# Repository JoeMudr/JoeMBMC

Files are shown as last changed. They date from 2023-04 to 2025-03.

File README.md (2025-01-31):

# JoeM BMC
Originally called "JoeM BMS" is now called "JoeM BMC" Battery Management Controller. Since it's not a complete BMS but only a controller for existing BMS-Modules.
This is the updated version for Teensy 4.0

This project is derived from [Toms SimpBMS code](https://github.com/Tom-evnut). It started as a clone (Software & Hardware) but ended up completely rewritten and redesigned. But you might still find some traces to the original code.

Complete documentation coming soon.

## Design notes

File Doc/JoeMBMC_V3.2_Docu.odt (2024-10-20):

JoeM BMC

Battery Management Controller
V3.2

# Introduction

This BMC (Battery Management Controller) is not a BMS on it’s own. It is designed to control OEM Battery Management Boards, Cell Monitoring Units or Battery Management Systems.

⚠ Although the BMC has been thoroughly tested, this is not a finished product. Some prior knowledge is required for commissioning. Use at your own risk!

# Pin Configuration

| A | B | C | D | E | F | G | H | J | K | L | M
1 | Out8 (PWM) | Out7 (PWM) | Out5 (PWM) | Out6 (PWM) | Out1 (12V) | Out2 (12V) | Out4 (12V) | Out3 (12V) | | | 12V | 12V
2 | BMB RX | BMB TX | Disp. RX | Disp. TX | ASen1 | ASen2 | In4 | In3 | In1 | In2
3 | GND | 5V | GND | 5V | GND | 5V
4 | CAN1-L | CAN1-H | CAN2-L | CAN2-H | 5V | USB D- | USB D+ | GND | | | GND | GND

All pins with the same symbol are internally connected.

All PWM-Outputs are tied to GND.

# Absolute maximum Ratings

Parameter | Symbol | Values | | | Unit
| | Min. | Typ. | Max.
Supply
Supply Voltage | 12V | 6 | 12 | 20* | V
Inputs
Voltage at In1 – In4 | VIN | 6 | 12 | 80 | V
ASen1 / Asen2 | VSen | 0 | - | 5 | V
Outputs
Current through OUT1 – Out4 (High) | IHOUT | - | - | 1 | A
Current through OUT5 – Out8 (Low) | ILOUT | - | - | 1 | A
5V | 5V | - | - | 0.5 | A

*Beware that the high side outputs are tied to the input voltage. It is technically possible to power the BMC with more than 12V. But all components controlled by the BMC on Out1 to Out4 should be able to withstand this high voltage.

# Wiring

## Precautions

- All wires for the power supply (L1,M1,L4,M4) should be 1mm². Add a fuse (10A) to the 12V line. It is not necessary to use both 12V and GND input pins.
- Do not use any other pin except L4 & M4 as your main GND connection!
- Do not feed any 5V pin with voltage! When intending to wire up and connect USB to your PC or any device that provides 5V over USB, do not connect the 5V pin! It might damage your USB-Port.
- Add 1A fuses to the outputs and use appropriate wire sizes.
- Use shielded wires for signals. Connect shielding to GND.

## Tesla Model S / X

Tesla Modules are daisy chained together. You start at the BMC Pin B2 (TX) which connects to the Molex connector of the Tesla board on Pin 2 or 7 (RX). Next you connect Pin 4 or Pin 9 (TX) to the next boards RX and so on. From the last board you connect the TX back to the BMC on Pin A2 (RX).

For power supply of the Tesla board use Pin B3 (5V) and A3 (GND) which connect to Pin 1 or 5 (5V) and Pin 3 or 8 (GND) respectively.

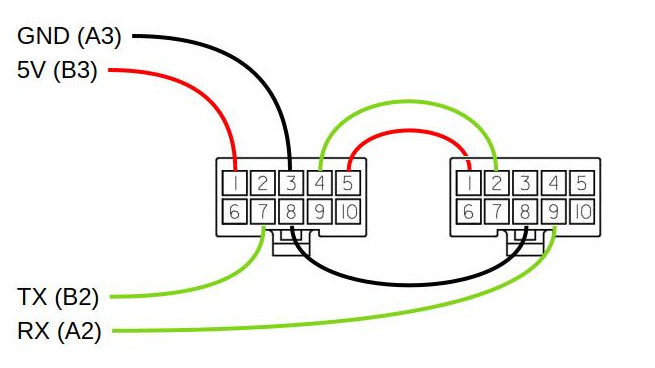
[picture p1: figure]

## VW MEB

Since the CMU connectors are not available on the free market, it’s important you keep the original connectors!

VW MEB Modules use CAN for communication. Therefor the CMUs must be connected in a kind of chain. One of the CMUs marks the end of the chain where a termination resistor must be activated.

Wire colors:

PIN | Function
1 | GND
2 | GND
3 | --
4 | TermR
5 | --
6 | TermR
7 | CAN High
8 | CAN High
9 | CAN Low
10 | CAN Low
11 | 12V
12 | 12V

Green-White 12V
Brown GND
Orange-Blue CAN High
Orange-Brown CAN Low

To use the termination resistor for example connect Pin 4 to Pin 7 and Pin 6 to Pin 9.

## BMW i3

# Configuration over USB

## Connecting via Terminal

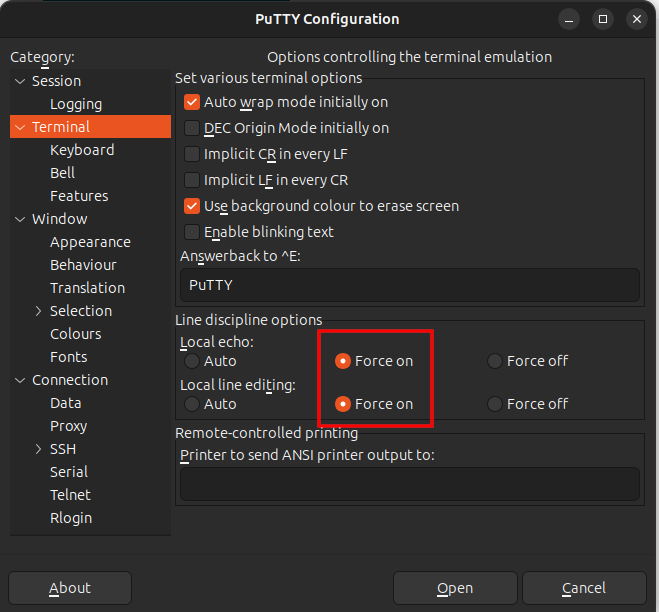
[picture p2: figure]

For a proper connection to the BMC use a terminal software such as putty (https://www.putty.org/). You can also use the Serial Monitor of the Arduino IDE. It’s important that the terminal software is set to use local echo and local line editing! Arduino IDE does this by default. In putty you find these settings under “Terminal”.

## Default Screen

Hotkeys:

b – toggle Modules / Cells display

o – toggle Output display

m – open Menu

## Configuration Menu

## Firmware Update

To update the BMC you need the latest firmware file from https://github.com/JoeMudr/JoeMBMC.
You also need the Teensy loader software from https://www.pjrc.com/teensy/loader.html.

Start the Teensy loader software and chose File → Open HEX File and select the Firmware.hex file.

Connect the BMC via USB. And open a Terminal. Press [M]+[Enter] to enter the main menu. In the main menu press [X]+[Enter]. This will reboot the micro controller to load the new firmware.

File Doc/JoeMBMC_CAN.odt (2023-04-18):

# CAN Messages

CAN ID 0x351 (send 1/sec) Limits
Byte | | Unit | Scale
1 | Charge Voltage High Byte | V | 0,1
2 | Charge Voltage Low Byte
3 | Charge Current High Byte | A | 0,1
4 | Charge Current Low Byte
5 | Discharge Current High Byte | A | 0,1
6 | Discharge Current Low Byte
7 | Discharge Voltage High Byte | V | 0,1
8 | Discharge Voltage Low Byte

CAN ID 0X355 (send 1/sec) SOC / SOH
Byte | | Unit | Scale
1 | SOC LowByte | % | 1
2 | SOC HighByte
3 | SOH LowByte | % | 1
4 | SOH HighByte
5 | SOC LowByte | % | 0,1
6 | SOC HighByte
7
8

CAN ID 0X356 (send 1/sec) Status
Byte | | Unit | Scale
1 | Pack Voltage LowByte | V | 0,01
2 | Pack Voltage HighByte
3 | Current LowByte | A | 0,1
4 | Current HighByte
5 | Av. Temperature LowByte | °C | 0,1
6 | Av. Temperature HighByte
7 | -
8 | -

CAN ID 0X35A (send 1/sec) Warnings / Alarms
Byte | | Unit | Scale
1 | alarm[0] | | 0 = OK, 1=Error
2 | alarm[1]
3 | alarm[2]
4 | alarm[3]
5 | warning[0] | | 0 = OK, 1=Error
6 | warning[1]
7 | warning[2]
8 | warning[3]

Bit | alarm[0] | alarm[1] | alarm[2] | alarm[3]
1 | - | Under Temperature | - | Cell Imbalance
2 | - | - | - | -
3 | Cell Over Voltage | - | - | -
4 | - | - | - | -
5 | Cell Low Voltage | - | - | -
6 | - | - | - | -
7 | Over Temperature | - | - | -
8 | - | - | - | -

Bit | warning[0] | warning[1] | warning[2] | warning[3]
1 | - | Under Temperature | - | -
2 | - | - | - | -
3 | Cell Over Voltage | - | - | -
4 | - | - | - | -
5 | Cell Low Voltage | - | - | -
6 | - | - | - | -
7 | Over Temperature | - | - | -
8 | - | - | - | -

CAN ID 0X372 (send 1/sec) Number of Modules
Byte | | Unit | Scale
1 | Number of Modules LowByte
2 | Number of Modules HighByte

CAN ID 0X373 (send 1/sec) Extreme Values
Byte | | Unit | Scale
1 | Low Cell Volt LowByte | V
2 | Low Cell Volt HighByte
3 | High Cell Volt LowByte | V
4 | High Cell Volt HighByte
5 | Low Temp. LowByte | K
6 | Low Temp. HighByte
7 | High Temp. LowByte | K
8 | High Temp. HighByte

CAN ID 0X372 (send 1/sec) Installed Capacity
Byte | | Unit | Scale
1 | Installed Capacity LowByte | Ah
2 | Installed Capacity HighByte

Plug | | BMS | | C
Plug connect
| AC conn / A max (contin.) →
| | Chk Cond. stat Charge
| ← Charge start
Close lock Chk Lock? charge en.
| Status →
| | Chk Stat.
| | | Charge start / A max →
| ← Charge stop | | Charge stop / A max = 0 →
Vehicle detec. Unlock?
Plug unconn. | Status (contin.) → | Chk if pres. Else → Err.

CAN Plug:

AC conn, Amax,

Status | Red LED | Green LED
norm | off | off
Plug connected | Blink slow | off
Charging / locked | on | Blink slow
Charged / locked | on | on
error | Blink fast | off

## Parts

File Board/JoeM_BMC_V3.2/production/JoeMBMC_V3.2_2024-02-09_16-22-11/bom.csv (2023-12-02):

Designator | Footprint | Quantity | Value | LCSC Part #
C1, C13, C14, C4 | 0805 | 4 | 100nF | C49678
C10, C11, C12, C9 | 0402 | 4 | 100p | C1546
C2, C3 | 0805 | 2 | 10uF | C15850
C5, C6, C7, C8 | C_Elec_6.3x7.7 | 4 | 100uF | C3001246
D1, D2, D3, D4 | D_SOD-123F | 4 | DIODE | C37049
D5, D6 | SOT-23 | 2 | NUP2105L | C284104
J1 | 5007620481 | 1 | 5007620481
J2 | PinHeader_1x02_P2.54mm_Vertical | 1 | CAN2_T
J3 | PinHeader_1x02_P2.54mm_Vertical | 1 | CAN1_T
Q1, Q2 | SO-8_IRF956 | 2 | BSO615NG | C693398
Q3 | TO-252-2 | 1 | P-Chanel Mosfet | C416264
R1, R10, R12, R14, R16, R18, R21, R26, R27, R28, R29, R30, R6, R7, R8, R9 | 0805 | 16 | 10k | C17414
R11, R13, R15, R17 | 0805 | 4 | 220 | C17557
R19, R22 | 0805 | 2 | 20k | C4328
R2, R3, R4, R5 | 0805 | 4 | 4.7k | C17673
R24, R25 | 0805 | 2 | 120 | C17437
R31, R32, R33, R34 | 0805 | 4 | 47k | C17713
S1 | PG-DSO-14-40_EP | 1 | BTS5200-4 | C534815
U1 | Teensy40_JoeMBMS | 1 | Teensy4.0
U2, U5 | SOIC-8_3.9x4.9mm_P1.27mm | 2 | SN65HVD230 | C12084
U3 | Converter_DCDC_RECOM_R-78E-0.5_THT | 1 | DCDC 5V
U4 | TLP293-4 | 1 | IS281-4 | C89878
U6 | Converter_DCDC_RECOM_R-78E-0.5_THT | 1 | DCDC 3.3V
U7, U8 | SOT-23-6 | 2 | Level Shifter 5V to 3V | C7843

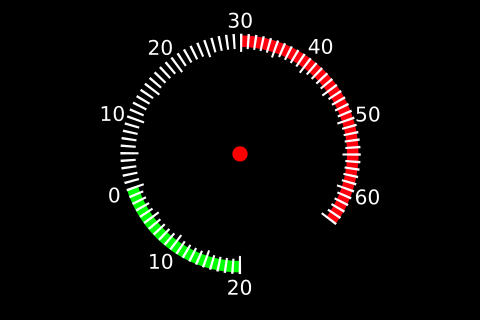
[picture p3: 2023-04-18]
BMSdisplay/components/Dash1_bg.png

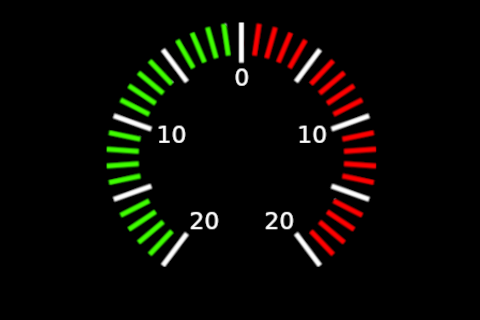
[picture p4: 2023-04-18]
BMSdisplay/components/Dash1_bg2.png

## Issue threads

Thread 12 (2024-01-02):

charge current limit via hardware

JoeMudr, 2024-01-02:
on the charge controller make the charge current selectable.
--> transmit to BMC

JoeMudr, 2024-03-24:
Feature for charge controller. Closed.

Closed 2024-03-24.

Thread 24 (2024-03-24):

Add Heating / Cooling request to BMC_Std CAN; Add option to menu

JoeMudr, 2024-03-24:
- Temperature Values configurable in menu

JoeMudr, 2024-03-26:
Current Implementation: Cooling/heating request can be read from temperature warnings from CAN ID 0x35A.
Warnings are raised from over/under temperature with warning offset configurable in the menu.
--> Maybe add separate options for temperature warnings.

JoeMudr, 2024-03-28:
see above

Closed 2024-03-28.

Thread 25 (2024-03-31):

Add optocouplers to all digital inputs

JoeMudr, 2024-03-31:
- replace level converter on serial lines
- add between CAN-Transceiver & Teensy

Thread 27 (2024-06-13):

current sensing on output

JoeMudr, 2024-06-13:
Add current sensing capabilities on all outputs for fault detection:
* contactor failure
* overcurrent detection

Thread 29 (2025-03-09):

Slowly increase charge current after 0A

JoeMudr, 2025-03-09:
Full charge current after Stat_Charged might overshoot charge voltage setpoint on slow inverters.
Make BMC slowly increase the charge current over a certain time span (30s?) when coming from 0A.

Closed 2025-03-23.

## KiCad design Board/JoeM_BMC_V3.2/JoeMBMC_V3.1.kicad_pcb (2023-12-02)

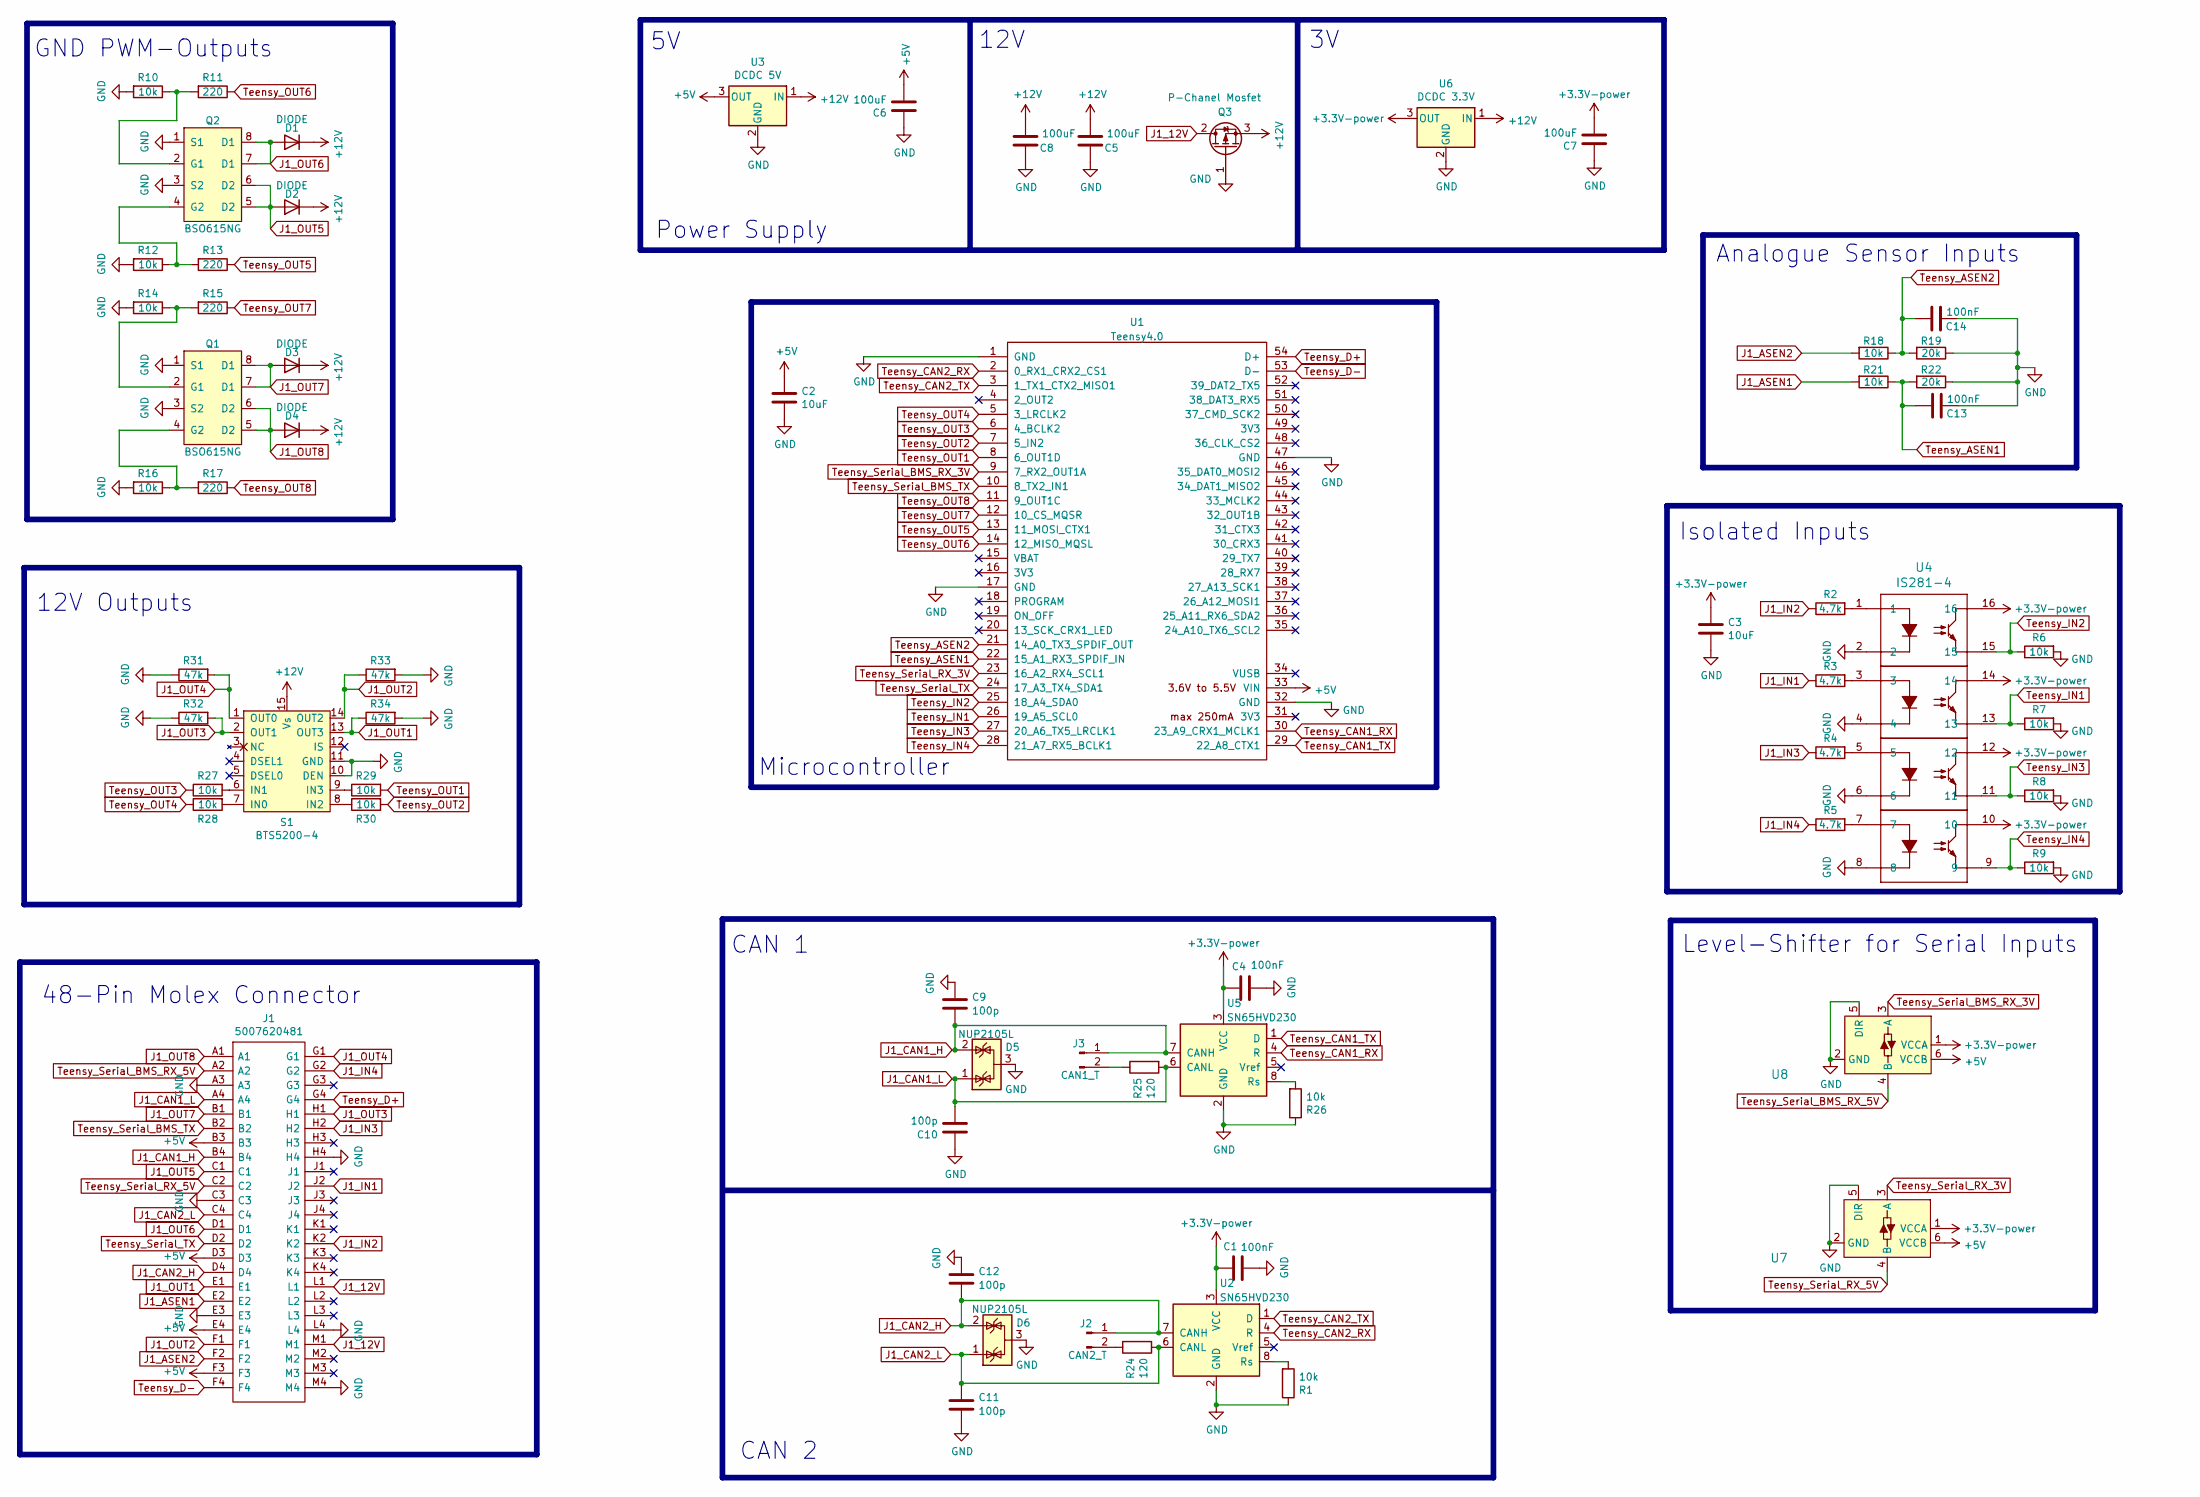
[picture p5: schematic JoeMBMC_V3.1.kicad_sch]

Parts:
C1, C4, C13, C14: 100nF; C_0805_2012Metric; LCSC C49678
C2, C3: 10uF; C_0805_2012Metric; LCSC C15850
C5, C6, C7, C8: 100uF; C_Elec_6.3x7.7; LCSC C3001246
C9, C10, C11, C12: 100p; C_0402_1005Metric; LCSC C1546
D1, D2, D3, D4: DIODE; D_SOD-123F; LCSC C8598
D5, D6: NUP2105L; SOT-23; LCSC C284104
J1: 5007620481; Manufacturer_Part_Number 5007620481
J2: CAN2_T; PinHeader_1x02_P2.54mm_Vertical
J3: CAN1_T; PinHeader_1x02_P2.54mm_Vertical
Q1, Q2: BSO615NG; SO-8_IRF956; LCSC C693398
Q3: P-Chanel Mosfet; TO-252-2; LCSC C416264
R1, R6, R7, R8, R9, R10, R12, R14, R16, R18, R21, R26, R27, R28, R29, R30: 10k; R_0805_2012Metric; LCSC C17414
R2, R3, R4, R5: 4.7k; R_0805_2012Metric; LCSC C17673
R11, R13, R15, R17: 220; R_0805_2012Metric; LCSC C17557
R19, R22: 20k; R_0805_2012Metric; LCSC C4328
R24, R25: 120; R_0805_2012Metric; LCSC C17437
R31, R32, R33, R34: 47k; R_0805_2012Metric; LCSC C17713
S1: BTS5200-4; PG-DSO-14-40_EP; LCSC C534815
U1: Teensy4.0; Teensy40_JoeMBMS
U2, U5: SN65HVD230; SOIC-8_3.9x4.9mm_P1.27mm; LCSC C12084
U3: DCDC 5V; Converter_DCDC_RECOM_R-78E-0.5_THT
U4: IS281-4; TLP293-4; LCSC C89878
U6: DCDC 3.3V; Converter_DCDC_RECOM_R-78E-0.5_THT
U7, U8: Level Shifter 5V to 3V; SOT-23-6; LCSC C7843

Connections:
+3V3: C1.2, C3.2, C4.2, C7.1, U2.3 (VCC), U4.10, U4.12, U4.14, U4.16, U5.3 (VCC), U6.3 (OUT), U7.1 (VCCA), U8.1 (VCCA); also elsewhere on the board
+5V: C2.2, C6.1, J1.B3, J1.D3, J1.E4, J1.F3, U1.33 (VIN), U3.3 (OUT), U7.6 (VCCB), U8.6 (VCCB); also elsewhere on the board
+12V: C5.1, C8.1, D1.1 (K), D2.1 (K), D3.1 (K), D4.1 (K), Q3.3 (S), S1.15 (Vs), U3.1 (IN), U6.1 (IN); also elsewhere on the board
GND: C1.1, C2.1, C3.1, C4.1, C5.2, C6.2, C7.2, C8.2, C9.1, C10.1, C11.2, C12.1, C13.1, C14.1, D5.3 (A), D6.3 (A), J1.A3, J1.C3, J1.E3, J1.H4, J1.L4, J1.M4, Q1.1 (S1), Q1.3 (S2), Q2.1 (S1), Q2.3 (S2), Q3.1 (G), R1.1, R6.2, R7.2, R8.2, R9.2, R10.2, R12.2, R14.2, R16.2, R19.1, R22.1, R26.1, R31.1, R32.1, R33.2, R34.2, S1.10 (DEN), S1.11 (GND), U1.1 (GND), U1.17 (GND), U1.32 (GND), U1.47 (GND), U2.2 (GND), U3.2 (GND), U4.2, U4.4, U4.6, U4.8, U5.2 (GND), U6.2 (GND), U7.2 (GND), U7.5 (DIR), U8.2 (GND), U8.5 (DIR)
J1_12V: J1.L1, J1.M1, Q3.2 (D)
J1_ASEN1: J1.E2, R21.2
J1_ASEN2: J1.F2, R18.2
J1_CAN1_H: C9.2, D5.2 (K), J1.B4, J3.1, U5.7 (CANH)
J1_CAN1_L: C10.2, D5.1 (K), J1.A4, R25.2, U5.6 (CANL)
J1_CAN2_H: C12.2, D6.2 (K), J1.D4, J2.1, U2.7 (CANH)
J1_CAN2_L: C11.1, D6.1 (K), J1.C4, R24.2, U2.6 (CANL)
J1_IN1: J1.J2, R3.1
J1_IN2: J1.K2, R2.1
J1_IN3: J1.H2, R4.1
J1_IN4: J1.G2, R5.1
J1_OUT1: J1.E1, R34.1, S1.13 (OUT3)
J1_OUT2: J1.F1, R33.1, S1.14 (OUT2)
J1_OUT3: J1.H1, R32.2, S1.2 (OUT1)
J1_OUT4: J1.G1, R31.2, S1.1 (OUT0)
J1_OUT5: D2.2 (A), J1.C1, Q2.5 (D2), Q2.6 (D2)
J1_OUT6: D1.2 (A), J1.D1, Q2.7 (D1), Q2.8 (D1)
J1_OUT7: D3.2 (A), J1.B1, Q1.7 (D1), Q1.8 (D1)
J1_OUT8: D4.2 (A), J1.A1, Q1.5 (D2), Q1.6 (D2)
unnamed: J2.2, R24.1
unnamed: J3.2, R25.1
unnamed: Q1.2 (G1), R14.1, R15.2
unnamed: Q1.4 (G2), R16.1, R17.2
unnamed: Q2.2 (G1), R10.1, R11.2
unnamed: Q2.4 (G2), R12.1, R13.2
unnamed: R2.2, U4.1
unnamed: R3.2, U4.3
unnamed: R4.2, U4.5
unnamed: R5.2, U4.7
unnamed: R28.2, S1.7 (IN0)
unnamed: R27.2, S1.6 (IN1)
unnamed: R30.1, S1.8 (IN2)
unnamed: R29.1, S1.9 (IN3)
unnamed: R1.2, U2.8 (Rs)
unnamed: R26.2, U5.8 (Rs)
Teensy_ASEN1: C13.2, R21.1, R22.2, U1.22 (15_A1_RX3_SPDIF_IN)
Teensy_ASEN2: C14.2, R18.1, R19.2, U1.21 (14_A0_TX3_SPDIF_OUT)
Teensy_CAN1_RX: U1.30 (23_A9_CRX1_MCLK1), U5.4 (R)
Teensy_CAN1_TX: U1.29 (22_A8_CTX1), U5.1 (D)
Teensy_CAN2_RX: U1.2 (0_RX1_CRX2_CS1), U2.4 (R)
Teensy_CAN2_TX: U1.3 (1_TX1_CTX2_MISO1), U2.1 (D)
Teensy_D+: J1.G4, U1.54 (D+)
Teensy_D-: J1.F4, U1.53 (D-)
Teensy_IN1: R7.1, U1.26 (19_A5_SCL0), U4.13
Teensy_IN2: R6.1, U1.25 (18_A4_SDA0), U4.15
Teensy_IN3: R8.1, U1.27 (20_A6_TX5_LRCLK1), U4.11
Teensy_IN4: R9.1, U1.28 (21_A7_RX5_BCLK1), U4.9
Teensy_OUT1: R29.2, U1.8 (6_OUT1D)
Teensy_OUT2: R30.2, U1.7 (5_IN2)
Teensy_OUT3: R27.1, U1.6 (4_BCLK2)
Teensy_OUT4: R28.1, U1.5 (3_LRCLK2)
Teensy_OUT5: R13.1, U1.13 (11_MOSI_CTX1)
Teensy_OUT6: R11.1, U1.14 (12_MISO_MQSL)
Teensy_OUT7: R15.1, U1.12 (10_CS_MQSR)
Teensy_OUT8: R17.1, U1.11 (9_OUT1C)
Teensy_Serial_BMS_RX_3V: U1.9 (7_RX2_OUT1A), U8.3 (A)
Teensy_Serial_BMS_RX_5V: J1.A2, U8.4 (B)
Teensy_Serial_BMS_TX: J1.B2, U1.10 (8_TX2_IN1)
Teensy_Serial_RX_3V: U1.23 (16_A2_RX4_SCL1), U7.3 (A)
Teensy_Serial_RX_5V: J1.C2, U7.4 (B)
Teensy_Serial_TX: J1.D2, U1.24 (17_A3_TX4_SDA1)

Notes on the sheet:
Analogue Sensor Inputs
GND PWM-Outputs
48-Pin Molex Connector
CAN 2
CAN 1
12V Outputs
Isolated Inputs
Microcontroller
Power Supply
12V
Level-Shifter for Serial Inputs

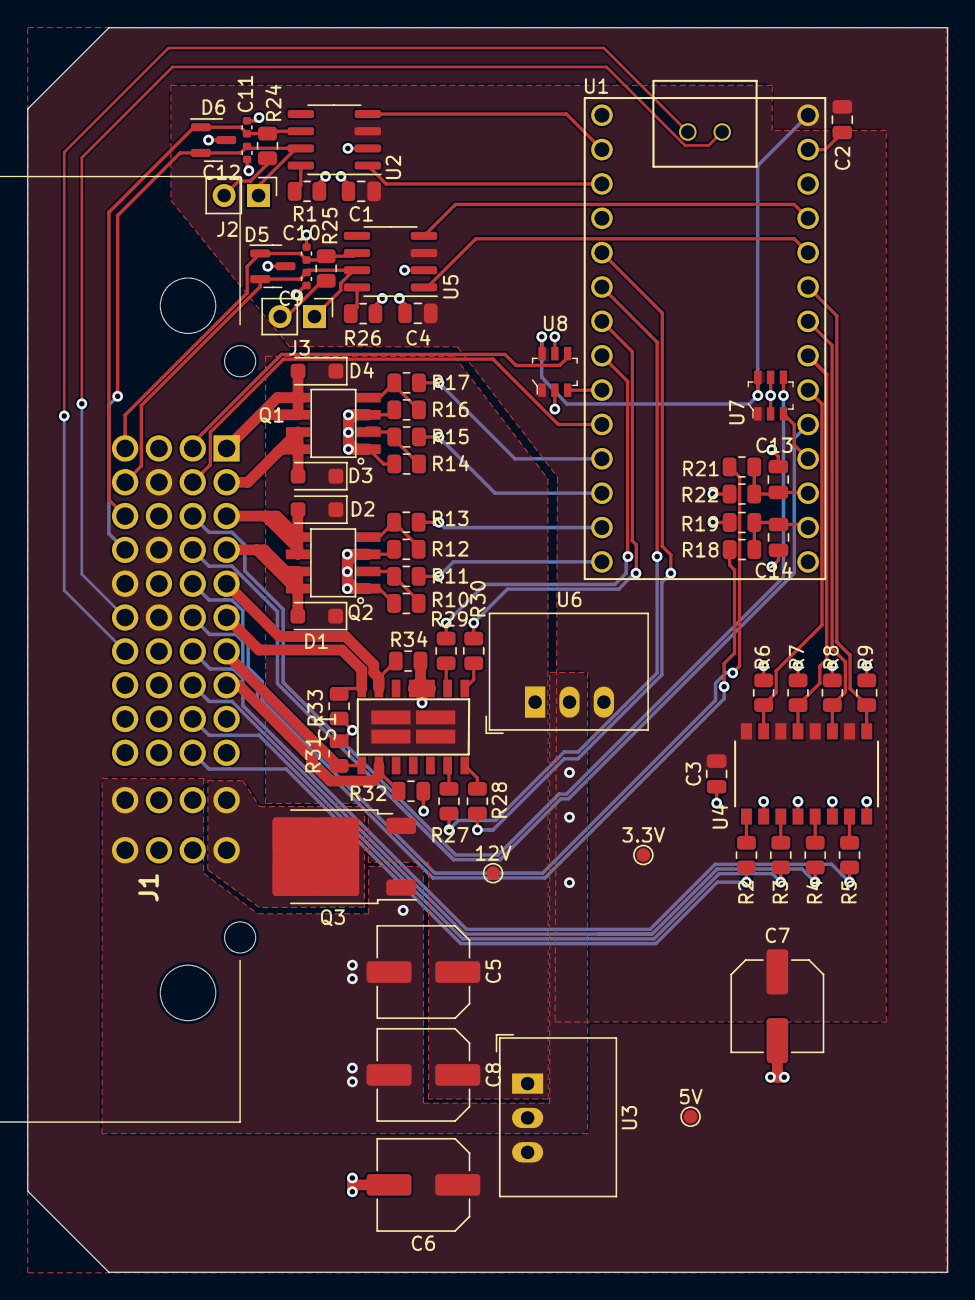
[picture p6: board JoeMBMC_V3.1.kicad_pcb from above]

Board: 2 copper layers, 68.0 x 92.0 mm, 70 parts (0 on the bottom side), 65 nets.

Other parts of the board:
3.3V, 5V, 12V: TestPoint_Pad_D1.0mm

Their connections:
+3V3: 3.3V.1; also elsewhere on the board
+5V: 5V.1; also elsewhere on the board
+12V: 12V.1; also elsewhere on the board

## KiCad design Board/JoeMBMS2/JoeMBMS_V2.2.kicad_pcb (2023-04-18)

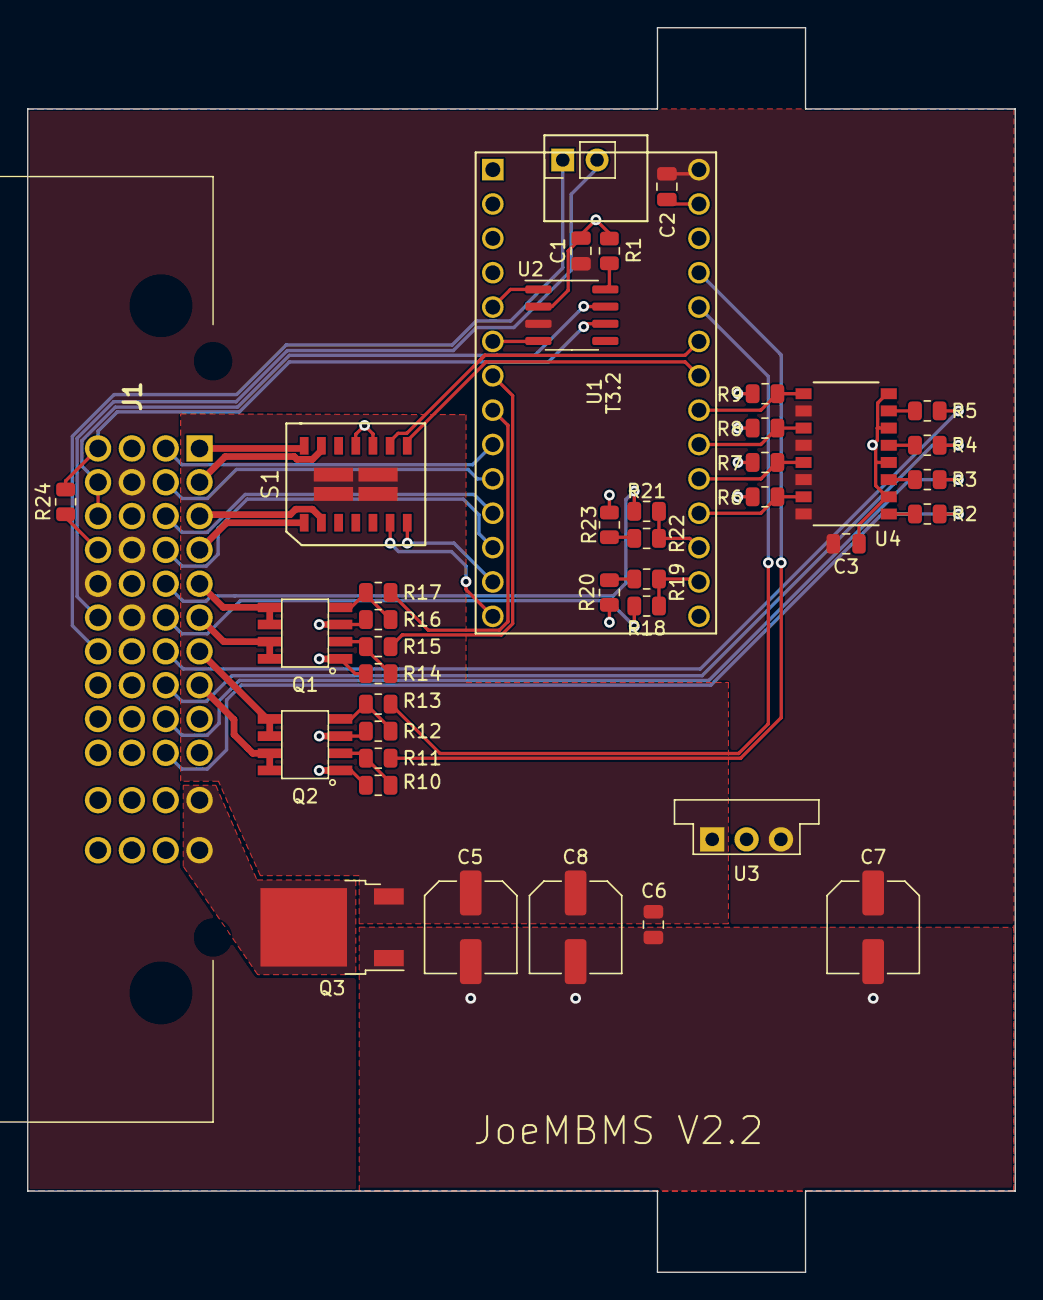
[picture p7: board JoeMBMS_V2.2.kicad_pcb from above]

Board: 2 copper layers, 73.0 x 92.0 mm, 40 parts (0 on the bottom side), 52 nets.

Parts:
C1: 100nF; C_0805_2012Metric
C2, C3, C6: 10uF; C_0805_2012Metric
C5, C7, C8: 100uF; C_Elec_6.3x7.7
J1: 5007620481
Q1, Q2: BSO615NG; SO-8_IRF956
Q3: P-Chanel Mosfet; TO-252-2
R1, R6, R7, R8, R9, R10, R12, R14, R16, R18, R19, R20, R21, R22, R23: 10k; R_0805_2012Metric
R2, R3, R4, R5: 4.7k; R_0805_2012Metric
R11, R13, R15, R17: 220; R_0805_2012Metric
R24: 120; R_0805_2012Metric
S1: BTS5200-4; PG-DSO-14-40_EP
U1: Teensy3.2; Teensy30_31_32_LC_Mod
U2: SN65HVD251; SOIC-8_3.9x4.9mm_P1.27mm
U3: DCDC 5V; Converter_DCDC_muRata_OKI-78SR_Vertical
U4: IS281-4; TLP293-4

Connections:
+12V: C5.1, C6.2, C8.1, Q3.3 (S), S1.15 (Vs), U3.1 (IN)
GND: C1.1, C2.1, C3.1, C5.2, C6.1, C7.2, C8.2, J1.A3, J1.C3, J1.E3, J1.H4, J1.L4, J1.M4, Q1.1 (S1), Q1.3 (S2), Q2.1 (S1), Q2.3 (S2), Q3.1 (G), R1.1, R6.2, R7.2, R8.2, R9.2, R10.2, R12.2, R14.2, R16.2, R20.1, R23.1, S1.10 (DEN), S1.11 (GND), U1.1 (GND), U1.32 (AGND), U2.2 (GND), U3.2 (GND), U4.2, U4.4, U4.6, U4.8
J1_12V: J1.L1, J1.M1, Q3.2 (D)
J1_ASEN1: J1.E2, R21.2
J1_ASEN2: J1.F2, R18.2
J1_CANH: J1.B4, J1.C4, U2.7 (CANH)
J1_CANL: J1.A4, R24.2, U2.6 (CANL)
J1_CAN_T_2: J1.D4, R24.1
J1_IN1: J1.J2, R3.1
J1_IN2: J1.K2, R2.1
J1_IN3: J1.H2, R4.1
J1_IN4: J1.G2, R5.1
J1_OUT1: J1.D1, S1.1 (OUT0)
J1_OUT2: J1.C1, S1.2 (OUT1)
J1_OUT3: J1.A1, S1.14 (OUT2)
J1_OUT4: J1.B1, S1.13 (OUT3)
J1_OUT5: J1.G1, Q2.5 (D2), Q2.6 (D2)
J1_OUT6: J1.H1, Q2.7 (D1), Q2.8 (D1)
J1_OUT7: J1.F1, Q1.7 (D1), Q1.8 (D1)
J1_OUT8: J1.E1, Q1.5 (D2), Q1.6 (D2)
J1_RX2: J1.C2, U1.11 (9_RX2_CS_PWM)
J1_TX2: J1.D2, U1.12 (10_TX2_CS_PWM)
unnamed: Q1.2 (G1), R14.1, R15.2
unnamed: Q1.4 (G2), R16.1, R17.2
unnamed: Q2.2 (G1), R10.1, R11.2
unnamed: Q2.4 (G2), R12.1, R13.2
unnamed: R1.2, U2.8 (Rs)
unnamed: R2.2, U4.1
unnamed: R3.2, U4.3
unnamed: R4.2, U4.5
unnamed: R5.2, U4.7
unnamed: R19.1, R20.2
unnamed: R22.1, R23.2
Teensy_ASEN1: R21.1, R22.2, U1.22 (15_A1_CS_Touch)
Teensy_ASEN2: R18.1, R19.2, U1.21 (14_A0_SCK)
Teensy_IN1: R7.1, U1.24 (17_A3_SDA0_Touch), U4.13
Teensy_IN2: R6.1, U1.23 (16_A2_SCL0_Touch), U4.15
Teensy_IN3: R8.1, U1.25 (18_A4_SDA0_Touch), U4.11
Teensy_IN4: R9.1, U1.26 (19_A5_SCL0_Touch), U4.9
Teensy_OUT1: S1.7 (IN0), U1.13 (11_DOUT)
Teensy_OUT2: S1.6 (IN1), U1.14 (12_DIN)
Teensy_OUT3: S1.8 (IN2), U1.27 (20_A6_CS_PWM)
Teensy_OUT4: S1.9 (IN3), U1.28 (21_A7_RX1_CS_PWM)
Teensy_OUT5: R13.1, U1.29 (22_A8_Touch_PWM)
Teensy_OUT6: R11.1, U1.30 (23_A9_Touch_PWM)
Teensy_OUT7: R15.1, U1.7 (5_TX1_PWM)
Teensy_OUT8: R17.1, U1.8 (6_PWM)
Teensy_RX: U1.6 (4_RX_PWM), U2.4 (R)
Teensy_RX3: J1.A2, U1.9 (7_RX3_DOUT)
Teensy_TX: U1.5 (3_TX_PWM), U2.1 (D)
Teensy_TX3: J1.B2, U1.10 (8_TX3_DIN)
Teensy_VUSB: C1.2, C2.2, C3.2, C7.1, J1.B3, J1.D3, J1.E4, J1.F3, U1.33 (Vin), U2.3 (VCC), U3.3 (OUT), U4.10, U4.12, U4.14, U4.16

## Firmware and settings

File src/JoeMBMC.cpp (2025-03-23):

/*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
  THE SOFTWARE IS PROVIDED "AS IS", WITHOUT WARRANTY OF ANY KIND,
  EXPRESS OR IMPLIED, INCLUDING BUT NOT LIMITED TO THE WARRANTIES OF
  MERCHANTABILITY, FITNESS FOR A PARTICULAR PURPOSE AND NONINFRINGEMENT.
  IN NO EVENT SHALL THE AUTHORS OR COPYRIGHT HOLDERS BE LIABLE FOR ANY
  CLAIM, DAMAGES OR OTHER LIABILITY, WHETHER IN AN ACTION OF CONTRACT,
  TORT OR OTHERWISE, ARISING FROM, OUT OF OR IN CONNECTION WITH THE
  SOFTWARE OR THE USE OR OTHER DEALINGS IN THE SOFTWARE.
*/

#include <JoeMBMC.h>
#include <Arduino.h>
#include <EEPROM.h>
#include <ADC.h>          //https://github.com/pedvide/ADC
#include <Filters.h>      //https://github.com/JonHub/Filters
#include <Watchdog_t4.h>  //https://github.com/tonton81/WDT_T4

Stream* activeSerial = &Serial_USB;

/////Version Identifier/////////
uint32_t firmver = 250323;

uint32_t Uptime = 0;

BMSManager bms;
EEPROMSettings settings;

//Curent filter//
byte filterFrequency = 5 ;
FilterOnePole lowpassFilter( LOWPASS, filterFrequency );

//BMC wiring//
//#define doesn't work here because Pins are used in Arrays below.
const byte IN_ACUR2 = A0;      // analogue current sensor 1
const byte IN_ACUR1 = A1;      // analogue current sensor 2
const byte IN_BOD = A10;       // brownout detection on ADC pin [ToDo]
const byte IN1_Key = 19;    // input 1 - high active
const byte IN2_Gen = 18;    // input 2 - high active
const byte IN3_AC = 20;     // input 3 - high active
const byte IN4_HVIL = 21;   // input 4 - high active
const byte OUT1 = 6;        // output 1 - high active
const byte OUT2 = 5;        // output 2 - high active
const byte OUT3 = 4;        // output 3 - high active
const byte OUT4 = 3;        // output 4 - high active
const byte OUT5 = 11;       // output 5 - Low active / PWM
const byte OUT6 = 12;       // output 6 - Low active / PWM
const byte OUT7 = 10;       // output 7 - Low active / PWM
const byte OUT8 = 9;        // output 8 - Low active / PWM
const byte LED = 13;

// uint32_t LED_Timer = 0;

byte BMC_Stat = 0;

//Serial Menu
bool menu_load = 0;

//Errors
uint32_t error_timer = 0;

byte Settings_unsaved = 0;

//variables for output control
uint16_t pwmfreq = 18000;//pwm frequency

uint16_t chargecurrent = 0;       // in 0,1A
uint16_t chargecurrentFactor = 0; // in%, correction factor, when using multiple chargers
uint16_t discurrent = 0;          // in 0,1A

/*
// SMA/Victron style Alarms & Warnings
// even Bits --> Alarm / Warning raised
// odd Bits --> Alarm / Warning cleared
[0] (7/6) hight Temp.          (5/4) low Voltage           (3/2) high Voltage           (1/0) general Alarm
[1] (7/6) high current         (5/4) low Temp. charge      (3/2) high Temp. charge      (1/0) low Temp.
[2] (7/6) Internal Failure     (5/4) battery short circuit (3/2) contactor problem      (1/0) high current charge
[3] (1/0) Cell Imbalance
*/
byte alarm[4],warning[4] = {0, 0, 0, 0};

// uint32_t warning_timer = 0;

unsigned char bmcname[8] = {'J', 'O', 'E', 'M', ' ', 'B', 'M', 'C'};
unsigned char bmcmanu[8] = {'J', 'O', 'E', 'M', ' ', 'T', 'E', 'C'};

//int32_t ISAVoltage1, ISAVoltage2, ISAVoltage3 = 0; //mV only with ISAscale sensor

uint32_t BMSLastRead = 0; // [ToDo] not used

//variables for current/capacity calulation
uint16_t Sen_AnalogueRawValue;
int32_t currentact = 0; // mA
int32_t currentlast = 0; // mA
int32_t RawCur;
int32_t mampsecond = 0; // Range 0 = full to settings.cap * -1 = empty
volatile int32_t mampsecondTimer = 0;
byte Sen_Analogue_active_Nr = 1; // active analogue sensor: 1 = Sensor 1; 2 = Sensor 2
int16_t TCAP = 0; //Temperature corrected Capacity in Ah including settings.Pstrings!
int16_t TCAP_Wh = 0;
//Variables for SOC calc
byte SOC = 100; //State of Charge

//charger variables Prusa
byte maxac1 = 16; //Shore power 16A per charger; only used for prusa charger
byte maxac2 = 10; //Generator Charging; only used for prusa charger
const int16_t chargerid1 = 0x618; //bulk chargers (brusa)
const int16_t chargerid2 = 0x638; //finishing charger (brusa)
uint16_t chargerendbulk = 0; //mV before Charge Voltage to turn off the bulk charger/s
uint16_t chargerend = 0; //mV before Charge Voltage to turn off the finishing charger/s


bool v_CAN_Charger_Active = false; // global variable for CAN-Based chargers
u_int32_t v_CAN_Charger_Active_Timer = 0; // Reset-timer for v_CAN_Charger_Active


//variables
byte storagemode = 0;
byte precharged = 0;

byte output_debug_counter = 0;

//Output Control
byte cont_pulltime = 255;

/*
Array for looping through outputs
OUT1 = 1, OUT2 = 2 ...
*/
const byte *Outputs[9] = {0,&OUT1,&OUT2,&OUT3,&OUT4,&OUT5,&OUT6,&OUT7,&OUT8};

/*
Array for function states & according timers for PWMs (full pull->reduced power)
[0][x] Function State (High/Low); [1][x] timer
*/
#define Out_States_Max 13
byte Out_States[2][Out_States_Max] = {{0,0,0,0,0,0,0,0,0,0,0,0,0},{0,cont_pulltime,cont_pulltime,cont_pulltime,0,0,0,0,0,0,0,0,0}}; 

/*
Text desctiptions for output funktions:
0 - undefined, 
1 - precharge Contactor, 
2 - positive Contactor, 
3 - negative Contactor, 
4 - Discharge enable, 
5 - Charge Enable, 
6 - Error, 
7 - Warning, 
8 - Error & Warning 
9 - Heating enable, 
10 - Cooling enable, 
11 - Gauge
12 - Balance enable
*/
String Out_Functions[] = {
  "undefined", 
  "precharge Cont.", 
  "positive Cont.", 
  "negative Cont.", 
  "Discharge enable", 
  "Charge enable", 
  "Error", 
  "Warning", 
  "Error & Warning",
  "Heating enable", 
  "Cooling enable", 
  "Gauge",
  "Balance enable"
};

//IDs for Array above
#define Out_undefined 0
#define Out_Cont_Precharge 1
#define Out_Cont_Pos 2
#define Out_Cont_Neg 3
#define Out_Discharge 4
#define Out_Charge 5
#define Out_Error 6
#define Out_Warning 7
#define Out_Err_Warn 8
#define Out_Heating 9
#define Out_Cooling 10
#define Out_Gauge 11
#define Out_Balance 12

//uint32_t Out_PWM_fullpull_Timer = 0; // PWM Timer

// CAN
FlexCAN_T4<CAN1> can1;
FlexCAN_T4<CAN2> can2;

// uint32_t CAN_BMC_Std_send_Timer = 0;

// Debugging modes
bool debug = 1;
bool debug_Input = 0;   // read digital inputs
bool debug_Output = 0;  // check outputs
bool debug_CAN1 = 0;    // view can frames
bool debug_CAN2 = 0;    // view can frames
bool debug_Gauge = 0;
byte  debug_Gauge_val = 0;
uint32_t debug_Gauge_timer = 0;
bool debug_Cur = 0;
bool debug_CSV = 0;
byte debug_Digits = 2; // amount of digits behind decimal for voltage reading

ADC *adc = new ADC(); // adc object

// TCU Variables
byte TCU_Pump = 0;
byte TCU_Cool = 0;
byte TCU_Heat = 0;
byte TCU_REL4 = 0;

IntervalTimer Timer_mAmpSec;

void loadDefaultSettings(){
  settings.version = EEPROM_VERSION;
  settings.checksum = 2;
  settings.ReadTimeout = 2000;
  settings.batteryID = 0x01;
  settings.BMSType = BMS_Dummy;
  settings.OverVAlarm = 4200;
  settings.OverVWarn = 4100;
  settings.ChargeVSetpoint = 4150;
  settings.UnderVWarn = 3200;
  settings.UnderVAlarm = 3000;
  settings.ChargeHys = 100; 
  settings.UnderVAlarm_DischHys = 200; 
  settings.CellGap = 500; 
  settings.OverTAlarm = 550; // 0.1°C
  settings.OverTWarn = 450; // 0.1°C
  settings.UnderTWarn = 50; // 0.1°C
  settings.UnderTAlarm = 0; // 0.1°C
  settings.ChargeOverTAlarm = 550; // 0.1°C
  settings.ChargeOverTWarn = 450; // 0.1°C
  settings.ChargeUnderTWarn = 50; // 0.1°C
  settings.ChargeUnderTAlarm = 0; // 0.1°C
  settings.useTempSensor = 0; 
  settings.IgnoreVolt = 500;
  settings.balanceVoltage = 3700;
  settings.balanceHyst = 10;
  settings.balanceDuty = 50;
  settings.CAP = 230; 
  settings.designCAP = 230; 
  settings.CAP_Wh = 25000;
  settings.Pstrings = 1;
  settings.Scells = 30;
  settings.StoreVsetpoint = 3800; 
  settings.OverCurrAlarm = 5500; 
  settings.OverCurrWarn = 5000; 
  settings.ChargerChargeCurrentMax = 320; 
  settings.ChargeOverCurrAlarm = 1000; 
  settings.ChargeOverCurrWarn = 950; 
  settings.ChargeCurrentEnd = 50; 
  settings.socvolt[0] = 3100; 
  settings.socvolt[1] = 10; 
  settings.socvolt[2] = 4100;
  settings.socvolt[3] = 90;
  settings.CurSenInvert = 0; 
  settings.CurSenType = Sen_Canbus;
  settings.voltsoc = 0; 
  settings.PreTime = 5000; 
  settings.PreCurrent = 1000; 
  settings.analogueSen2_convhigh = 312; 
  settings.analogueSen1_convlow = 1250; 
  settings.analogueSen1_offset = 1650; 
  settings.analogueSen2_offset = 1650;
  settings.analogueSen_ChangeCur = 140000;
  settings.GaugeLow = 0; 
  settings.GaugeHigh = 255; 
  settings.analogueSen_CurDead = 5;
  settings.ESSmode = 0; 
  settings.CurSenMultiplier = 1; 
  settings.nChargers = 1; 
  settings.ChargerType = Charger_Elcon; 
  settings.ChargerDirect = 1; 
  settings.mctype = 0; 
  settings.secondarySerial = 0; 
  settings.error_delay = 10000; 
  settings.Temp_CAP_Map[0][0] = -200;
  settings.Temp_CAP_Map[0][1] = -100;
  settings.Temp_CAP_Map[0][2] = 0;
  settings.Temp_CAP_Map[0][3] = 250;
  settings.Temp_CAP_Map[0][4] = 400;
  settings.Temp_CAP_Map[1][0] = 38;
  settings.Temp_CAP_Map[1][1] = 69;
  settings.Temp_CAP_Map[1][2] = 78;
  settings.Temp_CAP_Map[1][3] = 90;
  settings.Temp_CAP_Map[1][4] = 100;
  for (size_t i = 0; i < 9; i++){
    settings.Out_Map[0][i] = 0;
    settings.Out_Map[1][i] = 0;
  }
  settings.CAN1_Interval = 100; //ms per message
  settings.CAN2_Interval = 100; //ms per message
  settings.CAN1_Speed = 500000;
  settings.CAN2_Speed = 500000;
  for (size_t i = 0; i < 5; i++){
  settings.CAN_Map[0][i] = 0;
  settings.CAN_Map[1][i] = 0;
  }
  settings.SOC = 0;
  settings.Warning_Blink_Hz = 0;
  settings.Error_Blink_Hz = 0;
}

WDT_T4<WDT1> watchdog;
WDT_timings_t watchdog_config;

uint32_t lastResetCause;

void setup(){

  // Save copy of Reset Status Register
  lastResetCause = SRC_SRSR;
  // Clear all Reset Status Register bits
  SRC_SRSR = (uint32_t)0x1FF;

  pinMode(IN1_Key, INPUT);
  pinMode(IN2_Gen, INPUT);
  pinMode(IN3_AC, INPUT);
  pinMode(IN4_HVIL, INPUT);
  pinMode(OUT1, OUTPUT); // 12V output
  pinMode(OUT2, OUTPUT); // 12V output
  pinMode(OUT3, OUTPUT); // 12V output
  pinMode(OUT4, OUTPUT); // 12V output
  pinMode(OUT5, OUTPUT); // pwm GND output
  pinMode(OUT6, OUTPUT); // pwm GND output
  pinMode(OUT7, OUTPUT); // pwm GND output
  pinMode(OUT8, OUTPUT); // pwm GND output
  pinMode(LED, OUTPUT);

  analogWriteFrequency(OUT5, pwmfreq);
  analogWriteFrequency(OUT6, pwmfreq);
  analogWriteFrequency(OUT7, pwmfreq);
  analogWriteFrequency(OUT8, pwmfreq);

  EEPROM.get(0, settings);
  // manage EEPROM versions
  if (settings.version != EEPROM_VERSION){ loadDefaultSettings(); }
  
  can1_start();
  can2_start();

  //if using enable pins on a transceiver they need to be set on

  adc->adc0->setAveraging(16); // set number of averages
  adc->adc0->setResolution(16); // set bits of resolution
  adc->adc0->setConversionSpeed(ADC_CONVERSION_SPEED::HIGH_SPEED);
  adc->adc0->setSamplingSpeed(ADC_SAMPLING_SPEED::LOW_SPEED);
  adc->adc0->startContinuous(IN_ACUR1);

  //delay(2000);  //just for easy debugging. It takes a few seconds for USB to come up properly on most OS's  
  Serial_USB.begin(115200);
  Serial_USB.setTimeout(20);
  Serial_BT.begin(115200);
  activeSerial->printf("Starting up...\r\n");
  activeSerial->printf("JoeM BMC\r\n");
  //display serial
  Serial_Display.begin(115200); 
  //Tesla serial bus
  Serial_BMS.begin(612500);
  activeSerial->printf("Started serial interface to Tesla-BMS.\r\n");

  // enable WDT
  watchdog.begin(watchdog_config);

  BMSInit();

  Timer_mAmpSec.begin(mAmpsec_calc, 500000);
}

//called by Timer
void mAmpsec_calc(){ 
  uint32_t nowTime = millis();
  static uint32_t lastTime = 0;
  float tmpTime = 0;
  int32_t tmpmampsecond = 0;
  tmpTime = nowTime - lastTime;
  if((nowTime - lastTime) < 0){tmpTime = 4294967295 - lastTime + nowTime;} // Catch millis() overflow [ToTest]
  tmpmampsecond = ((currentact+currentlast)/2 * tmpTime / 1000);
  mampsecondTimer += tmpmampsecond;
  currentlast = currentact;
  lastTime = millis();  
}

void loop(){
  static byte Modules_Print_ON = 1;
  static byte Out_Print_ON = 0;

  BMC_Status_LED();
  //BOD(analogRead(IN_BOD)); // [ToDo] detect voltage drop on 12V side
  
  //everything CAN related happens here
  CAN_read();

  if ( settings.CurSenType == Sen_AnalogueDual || settings.CurSenType == Sen_AnalogueSing){
    currentact = SEN_AnalogueRead(currentlast);
  }

  // make serial console available after 3s
  if (millis() > 3000 && activeSerial->available()){
    String tmp_String = activeSerial->readString();
    tmp_String.trim();
    if(menu_load){Menu(tmp_String);}
    else{
      if(tmp_String == 'o'){Out_Print_ON = !Out_Print_ON;}
      if(tmp_String == 'b'){Modules_Print_ON = !Modules_Print_ON;}
      if(tmp_String == "menu"){menu_load = 1; Menu();}
    }
  }

  WarnAlarm_Check();

  if (!debug_Output){
    if (settings.ESSmode){BMC_Stat = ESS_CondCheck(BMC_Stat);}
    else {BMC_Stat = Vehicle_CondCheck(BMC_Stat);}
    BMC_Statemachine(BMC_Stat);
    set_OUTs();
  }

  if(debug_Cur){Current_debug();}

  // Poll the BMS/CMUs
  // Interval restrictions are managed in BMSManager.cpp
  CAN_Struct CAN_Msg;
  CAN_Msg = bms.poll();
  for (byte CANMsgNr = 0; CANMsgNr < CAN_Struct_size; CANMsgNr++){
    if (CAN_Msg.Frame[CANMsgNr].id){ // bms.poll() returns a previously cleaned CAN_Struct. We only send actually filled Frames.
      if (settings.CAN_Map[0][CAN_BMS] & 1){can1.write(CAN_Msg.Frame[CANMsgNr]);}
      if (settings.CAN_Map[0][CAN_BMS] & 2){can2.write(CAN_Msg.Frame[CANMsgNr]);}
      delay(1);
    }
  }

  // 1s loop
  static uint32_t looptime_1s = 0;
  if (millis() - looptime_1s > 1000){
    looptime_1s = millis();
    Uptime++;
  }

  // 0.5s loop
  static uint32_t looptime = 0;
  if (millis() - looptime > 500){ 
    looptime = millis();
    
    // TCAP is negative. 0 = full, settings.CAP * -1 is empty.
    TCAP = settings.Pstrings * CAP_Temp_alteration() * -1;
    TCAP_Wh = TCAP * round(double(bms.getPackVoltage()) / 1000) * -1; // [ToDo] value will fluctuate

    // copy Ampseconds from Timer Funktion
    noInterrupts();
    mampsecond += mampsecondTimer;
    if(mampsecond > 0){mampsecond = 0;}
    mampsecondTimer = 0;
    interrupts();

    if (!menu_load){ 
      // main debug output
      Serial_Print(Modules_Print_ON); 
      // OUT functions and states
      OUT_print(Out_Print_ON);
      // Display reason the Teensy was last reset
      Reset_Cause(lastResetCause);
    } //"debug" output on serial console
    //if (debug_CSV){ bms.printAllCSV(millis(), currentact, SOC); }
    if (debug_Input){ Input_Debug(); }
    if (debug_Output){ Output_debug(); }
    else{ Gauge_update(); }
    
    SOC_update();
    Currentavg_Calc();

    if (settings.secondarySerial == 0){ Dash_update(); }//Info on serial bus 2
    //if (settings.secondarySerial == 2){ BT_update(); }// --> Bluetooth App
    //WDT reset;
    watchdog.feed();
  }
}

/* ==================================================================== */
// i.MX RT1060 Processor Reference Manual, 21.8.3 SRC Reset Status Register
void Reset_Cause(uint32_t resetStatusReg) {
  bool info = false;
  activeSerial->printf("\r\nReason for last Reset: ");
  if (resetStatusReg & SRC_SRSR_TEMPSENSE_RST_B) {
      activeSerial->printf("Temperature Sensor Software Reset\r\n");
      info = true;
  }
  if (resetStatusReg & SRC_SRSR_WDOG3_RST_B) {
      activeSerial->printf("IC Watchdog3 Timeout Reset\r\n");
      info = true;
  }
  if (resetStatusReg & SRC_SRSR_JTAG_SW_RST) {
      activeSerial->printf("JTAG Software Reset\r\n");
      info = true;
  }
  if (resetStatusReg & SRC_SRSR_JTAG_RST_B) {
      activeSerial->printf("High-Z JTAG Reset\r\n");
      info = true;
  }
  if (resetStatusReg & SRC_SRSR_WDOG_RST_B) {
      activeSerial->printf("IC Watchdog Timeout Reset\r\n");
      info = true;
  }
  if (resetStatusReg & SRC_SRSR_IPP_USER_RESET_B) {
      activeSerial->printf("Power-up Sequence (Cold Reset Event)\r\n");
      info = true;
  }
  if (resetStatusReg & SRC_SRSR_CSU_RESET_B) {
      activeSerial->printf("Central Security Unit Reset\r\n");
      info = true;
  }
  if (resetStatusReg & SRC_SRSR_LOCKUP_SYSRESETREQ) {
      activeSerial->printf("CPU Lockup or Software Reset\r\n");
      info = true;
      /* Per datasheet: "SW needs to write a value to SRC_GPR5
       * before writing the SYSRESETREQ bit and use the SRC_GPR5
       * value to distinguish if the reset is caused by SYSRESETREQ
       * or CPU lockup."
       */
  }
  if (resetStatusReg & SRC_SRSR_IPP_RESET_B) {
      activeSerial->printf("Power-up Sequence\r\n");
      info = true;
  }
  if (!info) {
      activeSerial->printf("No status bits set in SRC Reset Status Register\r\n");
  }
}

void BOD(int16_t ADC_read){
  if (ADC_read <= 4000){
    activeSerial->printf("::::::::::::::::::::::::BOD triggered::::::::::::::::::::::::\r\n");
    settings.SOC = SOC;
    EEPROM.put(0,settings);
  }
}

void BMSInit(){
  bms.initBMS(settings.BMSType,settings.IgnoreVolt,settings.useTempSensor,settings.ReadTimeout);
}

// Returns 1 if requested Warning or Alarm is raised. Type 0 = ignored, 1 = Warning, 2 = Error
bool WarnAlarm_Check(byte Type, byte WarnAlarm){
  static uint32_t warning_timer = 0;
  byte hyst = 5; // 0.5°C hysteresis [ToDO] make config.

  // reset to all OK
  for(byte i = 0; i<4; i++){
    warning[i] = 0b10101010;
    alarm[i] = 0b10101010;
  } 

  // Overvoltage
  if (bms.getHighCellVolt() > settings.OverVWarn){warning[0] ^= 0b00001100;}  
  if (bms.getHighCellVolt() > settings.OverVAlarm){alarm[0] ^= 0b00001100;}

  // Undervoltage
  if (bms.getLowCellVolt() < (settings.UnderVWarn)){
    warning[0] ^= 0b00110000;
    if (!warning_timer){warning_timer = millis() + 10000;}
    if (millis() > warning_timer){CAP_recalc();warning_timer = 0;} // recalculate capacity when lowest cell is under warning setpoint; reset Timer to prevent EEPROM Kill
  } else {warning_timer = 0;}    
  if (bms.getLowCellVolt() < settings.UnderVAlarm){alarm[0] ^= 0b00110000;}

  // Over Temperature 
  if (bms.getHighTemperature() > settings.OverTWarn){warning[0] ^= 0b11000000;}  
  if (bms.getHighTemperature() > settings.OverTAlarm){alarm[0] ^= 0b11000000;}

  // Under Temperature
  if (bms.getLowTemperature() < settings.UnderTWarn){warning[1] ^= 0b00000011;}  
  if (bms.getLowTemperature() < settings.UnderTAlarm){alarm[1] ^= 0b00000011;}

  // Charge Over Temperature
  if (bms.getHighTemperature() > settings.ChargeOverTWarn){warning[1] ^= 0b00001100;}
  if (bms.getHighTemperature() > settings.ChargeOverTAlarm){alarm[1] ^= 0b00001100;}

  // Charge Under Temperature
  if (bms.getLowTemperature() < settings.ChargeUnderTWarn){warning[1] ^= 0b00110000;}
  if (bms.getLowTemperature() < settings.ChargeUnderTAlarm){alarm[1] ^= 0b00110000;}

  // Over Current
  if (currentact / 100 * -1 > settings.OverCurrWarn){warning[1] ^= 0b11000000;}
  if (currentact / 100 * -1 > settings.OverCurrAlarm){alarm[1] ^= 0b11000000;}

  // Charge Over Current
  if (currentact / 100 > settings.ChargeOverCurrWarn){warning[2] ^= 0b00000011;} 
  if (currentact / 100 > settings.ChargeOverCurrAlarm){alarm[2] ^= 0b00000011;}

  // External Alarm / Series Cells [ToDo] include BMB/CMU Alerts
  if (bms.getSeriesCells() != settings.Scells * settings.Pstrings){warning[2] ^= 0b11000000;}
//if (bms.getSeriesCells() != settings.Scells * settings.Pstrings){alarm[2] ^= 0b11000000;} // [ToDo] elaborate

  // Cell Gap
  if ((bms.getHighCellVolt() - bms.getLowCellVolt()) > settings.CellGap){warning[3] ^= 0b00000011;}
//if ((bms.getHighCellVolt() - bms.getLowCellVolt()) > settings.CellGap){alarm[3] ^= 0b00000011;} // [ToDo] elaborate


  switch (WarnAlarm){
    case WarnAlarm_VLow:
      if(Type == 1){return warning[0] & 0b00010000;}
      if(Type == 2){return alarm[0] & 0b00010000;}
    break;
    case WarnAlarm_Vhigh:
      if(Type == 1){return warning[0] & 0b00000100;}
      if(Type == 2){return alarm[0] & 0b00000100;}
    break;
    case WarnAlarm_ChargeTLow:
      if(Type == 1){return warning[1] & 0b00010000;}
      if(Type == 2){return alarm[1] & 0b00010000;}
    break;
    case WarnAlarm_ChargeTHigh:
      if(Type == 1){return warning[1] & 0b00000100;}
      if(Type == 2){return alarm[1] & 0b00000100;}
    break;
    case WarnAlarm_TLow:
      if(Type == 1){return warning[1] & 0b00000001;}
      if(Type == 2){return alarm[1] & 0b00000001;}
    break;
    case WarnAlarm_THigh:
      if(Type == 1){return warning[0] & 0b01000000;}
      if(Type == 2){return alarm[0] & 0b01000000;}
    break;
    case WarnAlarm_CurHigh:
      if(Type == 1){return warning[1] & 0b01000000;}
      if(Type == 2){return alarm[1] & 0b01000000;}
    break;
    case WarnAlarm_ChargeCurHigh:
      if(Type == 1){return warning[2] & 0b00000001;}
      if(Type == 2){return alarm[2] & 0b00000001;}
    break;
    case WarnAlarm_External:
      if(Type == 1){return warning[2] & 0b01000000;}
      if(Type == 2){return alarm[2] & 0b01000000;}
    break;
    case WarnAlarm_CellGap:
      if(Type == 1){return warning[3] & 0b00000001;}
      if(Type == 2){return alarm[3] & 0b00000001;}
    break;
    
    default: // return 1 if any Warning or Alarm is raised. No specific WarnAlarm passed (=0=Dummy).
      if(Type == 1){if (warning[0] & 0b01010101 || warning[1] & 0b01010101 || warning[2] & 0b01010101 || warning[3] & 0b01010101) {return 1;}}
      if(Type == 2){if (alarm[0] & 0b01010101 || alarm[1] & 0b01010101 || alarm[2] & 0b01010101 || alarm[3] & 0b01010101) {return 1;}} 
    break;
  }
  return 0;
}
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

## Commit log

2023-04-18 clean old Board files
    [82548PLCC-2_package_3D.stp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]
2023-10-21 Upgrade Teensy 3.2 -> 4.0
    [JoeMBMS_V2.0.kicad_pcb, JoeMBMS_V2.0.sch, JoeMBMS_V2.2.kicad_sch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]
2023-11-11 Board Updates for 3.3V
    [JoeMBMS_V2.2-B_Cu.gbr, JoeMBMS_V2.2-B_Mask.gbr, JoeMBMS_V2.2-B_Paste.gbr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]
2023-11-17 Update Board V3.1
    [Infineon_PG-LLGA-5-1.FCStd, JoeMBMS_V3.1.kicad_pcb, JoeMBMS_V3.1.kicad_sch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]
2023-11-26 Rename & Cleanup
    [82548PLCC-2_package_3D.stp, JoeMBMS_V2.2.kicad_pcb, JoeMBMS_V2.2.kicad_sch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]
2023-11-26 Git Test
    [JoeMBMS_V3.1.kicad_pcb, JoeMBMS_V3.1.kicad_sch]
2023-12-02 remove zener on analogue sensor inputs
    [JoeMBMC_V3.1.kicad_pcb, JoeMBMC_V3.1.kicad_sch, bom.csv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]
2023-12-20 CAN rearrange & debug, Gauge-Fix
    [JoeMBMC.cpp]
2024-01-02 Board Backups
2024-01-02 Check for ChargerDirect in vehicle mode
2024-01-06 Teensy moved; USB clearance
    [JoeMBMC_V3.2.kicad_pcb]
2024-01-08 Board redesign
    [JoeMBMC_V3.2.kicad_pcb, bom.csv, designators.csv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]
2024-01-08 Warn_handle() does no use the correct warning values #19
    [JoeMBMC.cpp]
2024-01-09 #16 start adding VW BMS
2024-01-24 Complete rewrite of BMS-Libs for #16, VW & Tesla S/X included
2024-01-28 outsource CANOpen, minor fixes, cleanup some ToDos
    [JoeMBMC.cpp]
2024-02-05 minor fixes: abs -> labs; current without floats; fixes in Menu (former floats); fix constrains; add ReadTimeout
    [JoeMBMC.cpp]
2024-02-05 move BMS timeout to BMSManager; float -> double typecast for 32bit values; restructure SOC_update()
2024-02-05 rearranging debug output; reset values in BMSinit() to use BMSinit() as reset.
    [JoeMBMC.cpp]
2024-02-17 replace print/println by printf
    [JoeMBMC.cpp]
2024-02-17 USB traces closer together
    [JoeMBMC_V3.2.kicad_pcb, bom.csv, designators.csv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]
2024-02-18 fix Reboot; adjust debug output; add binary conversion
    [JoeMBMC.cpp]
2024-03-13 Board Updates
    [JoeMBMC_V3.2.kicad_pcb]
2024-03-22 modify BMS poll for BMW i3
2024-03-24 prepare #23; add value change check für current sensors.
2024-03-24 Fixes: SOC calc; TSensors Average
    [JoeMBMC.cpp]
2024-03-24 Fixes: Display; Serial clear
    [JoeMBMC.cpp]
2024-03-27 Add TCU Comm; Fixes: AVGTemp, Balancing Stop.
    [JoeMBMC.cpp]
2024-03-27 Reduced CANStruct size; removed some global variables in BMSManager
2024-03-29 Add separate Charge/discharge Limits #14
2024-03-29 #18 prev. commit with wrong issue nr.
    [JoeMBMC.cpp]
2024-03-30 Fixes: Alarms&Warnings bits missing; Restructure CondChecks; Add State Stat_Discharge -> ESS, CondCheck
    [JoeMBMC.cpp]
2024-04-27 Fix for HV-CAN-Protocol: Wrong Temp conversion
    [JoeMBMC.cpp]
2024-04-27 Board: removed old Backups
2024-04-28 fix ETA; remove CAN_BMC_Std from Stat_Charged; Fix CurrentAVG; Fix CAN-HV-Protocl current
    [JoeMBMC.cpp]
2024-04-29 Fix Pylontech HV Under Temp issue
    [JoeMBMC.cpp]
2024-05-22 board Backup cleanup
2024-06-01 Menu option for Battery ID; Battery ID added to HV CAN messages; additional value types for menu options
2024-06-14 restructure Folder
    [JoeMBMC_V3.1.kicad_pcb, JoeMBMC_V3.1.kicad_sch, JoeMBMC_V3.2.kicad_pcb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]
2024-06-28 fix includes; add Power in CAN ID 379
    [JoeMBMC.cpp]
2024-10-06 Rename Statemachine; Add CAN-Bus charge indication
2024-10-06 Board revisions
2024-10-20 Doc: Max-Voltages reduced for Mosfet.
2024-10-20 Fix moduleReadCnt; Try adding BOD; make vars local,static if possible; Add SOC to Settings struct; change Serial Read to string & trim(); rename some vars
    [JoeMBMC.cpp]
2024-10-20 no changes
    [JoeM_BMC_V3.2.kicad_pcb]
2024-10-20 removed Board Backups & Putty Logs
2024-10-20 make Currentavg_calc vars private static; assign HVIL to IN4; changes to current display on debug screen.
2024-10-27 fix ETA / currentavg_calc()
    [JoeMBMC.cpp]
2024-10-27 #28 add "blinking" to Errors/Warnings
    [JoeMBMC.cpp]
2024-12-02 fix PWM Contactor control; simplify CAN_SEN_read()
    [JoeMBMC.cpp]
2024-12-06 Fix missing Outputs in Stat_Charge
    [JoeMBMC.cpp]
2024-12-26 Add ChargeCurrentLimit() ti Stat_Drive; fix ChargeCurrentLimit; Add TLow-Check to DischargeCurrentLimit()
    [JoeMBMC.cpp]
2024-12-28 ChargeCurrentLimit(): use smaler Value from ChargerChargeCurrentMax or ChargeOverCurrAlarm
2025-01-06 Added Uptime; Added AlarmDischargeHyst for heating / cooling; restructured Battery menu
2025-01-12 cleanup; Add Power (mW) to debug screen.
2025-01-31 charge / dischargecurrent mapping oflerflow fixed
    [JoeMBMC.cpp]
2025-02-02 Change Battery Menu Temperature layout
2025-02-02 non-linear charge derating
2025-02-02 add charge hysteresis for stat_charged in ESS mode
2025-02-09 fix ESS_CondCheck; expand chargecurrent taper to full hysteresis
    [JoeMBMC.cpp]
2025-02-22 Fix balancing not resetting (Tesla); Fix balancing missing output (VW MEB)
    [JoeMBMC.cpp]
2025-02-22 Fix chargecurrentfactor
2025-03-09 slowly increase charge current after 0A
2025-03-23 remove 30 chargecurrent taoering for current feedbackloop.
